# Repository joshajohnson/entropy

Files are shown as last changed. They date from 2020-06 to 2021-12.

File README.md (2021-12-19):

# Entropy

## A 96% Southpaw keyboard, with split space and encoder support. 

Entropy started as a STM32 powered keyboard running QMK and enclosed in a FR4 and PLA case, but at the time of writing runs on a nRF52 and ZMK, tucked inside a stacked acrylic case.

ZMK enables wireless functionality, and you'll get upwards of 6 months battery life thanks to the 200uA sleep current.

It also supports up to 4 rotary incoders in 5 different positions, along with a myriad of layout options.

## Photos
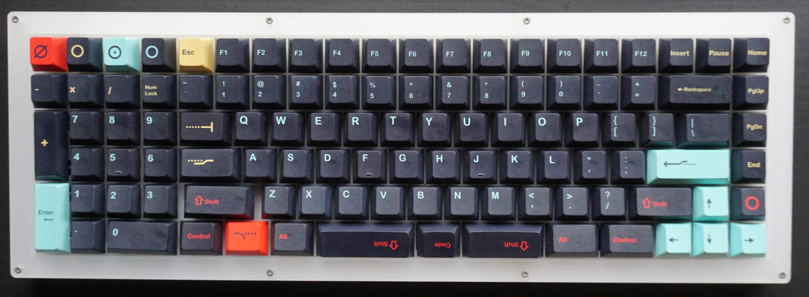
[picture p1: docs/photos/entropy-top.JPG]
Top View

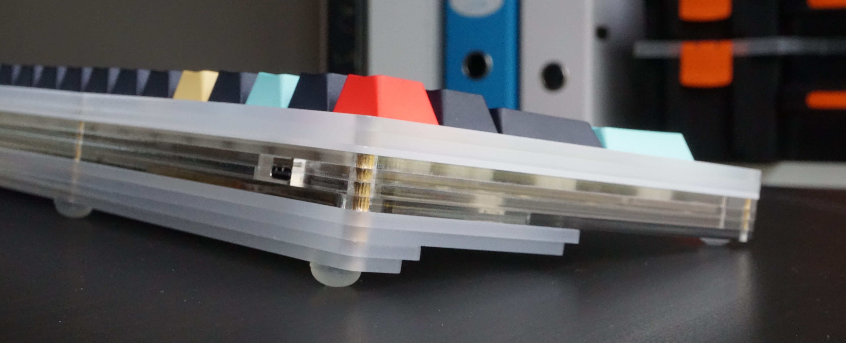
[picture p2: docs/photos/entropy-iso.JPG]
Side View

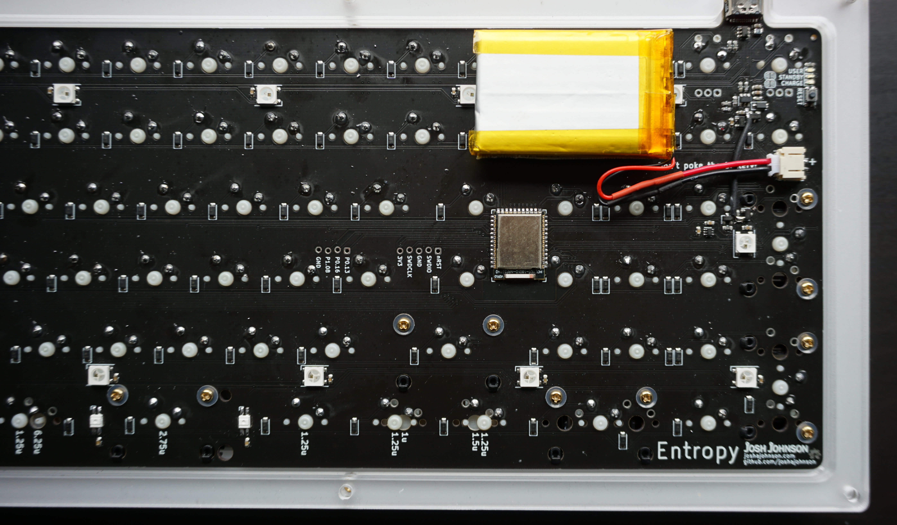
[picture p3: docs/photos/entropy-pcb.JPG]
Battery and Power Circuit


## Layout
Supports Encoders in (0,0)...(0,3) and (0,19)

ZMK versions only allow 4 encoders to be populated (hiting interrupt limit with 5 encoders)
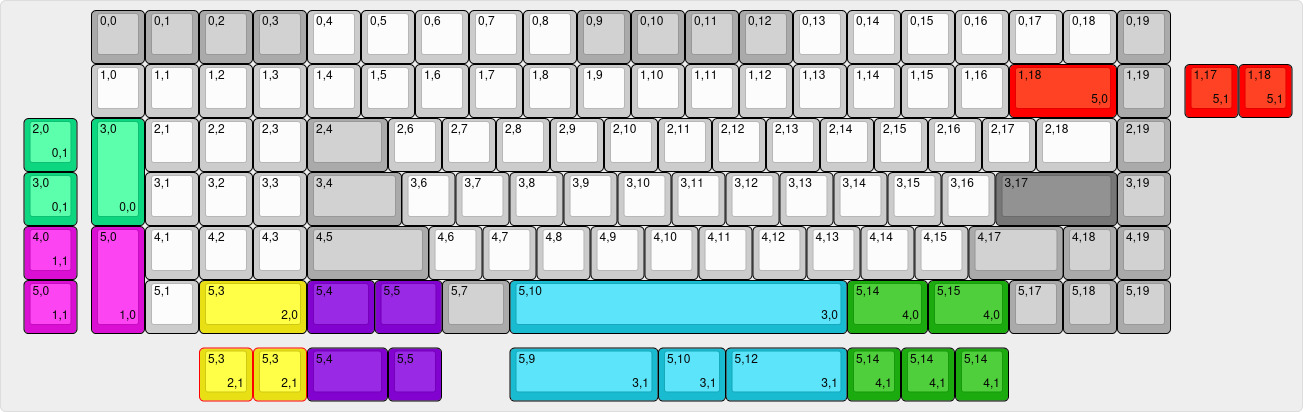
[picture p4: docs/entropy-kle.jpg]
KLE


## Revision History

R0.1: 
- Original STM32 design, no bugs that can't be worked around. 
- Tested and working.

R0.2: 
- Removed overengineering, modified to suit JLCSMT. 
- Fixed plate 2U tight fit. 
- **Has known issues with powering the LEDs, do not use**

### Image of R0.1 and R0.2 Design
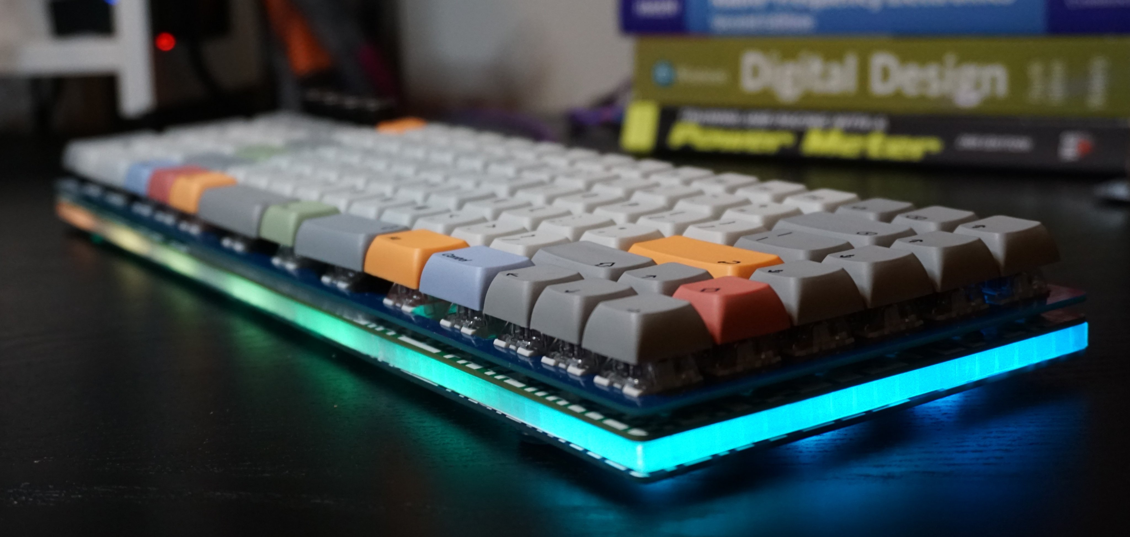
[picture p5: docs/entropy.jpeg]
R0.1 and R0.2 Assembled Keyboard


R0.3: 

- Moved to nRF52840 and ZMK due to supply issues with the STM32F303 used in R0.1 and R0.2.
- Case design changed to plate mount in stacked acrylic case.
- Design moved to KiCad V6.

R0.4: 
- Battery life and design improvements over R0.3. 
- Few issues requiring rework but suitable for use.

R0.5: 
- Resolved issues found in R0.4, however untested. 
- **Use at your own risk.**

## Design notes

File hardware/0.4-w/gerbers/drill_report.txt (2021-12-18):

Drill report for keyboard.kicad_pcb
Created on Sun Aug 29 18:12:00 2021

Copper Layer Stackup:
    =============================================================
    L1 :  F.Cu                      front
    L2 :  B.Cu                      back

Drill file 'keyboard.drl' contains
    plated through holes:
    =============================================================
    T1  0.300mm  0.0118"  (581 holes)
    T2  0.400mm  0.0157"  (81 holes)
    T3  0.600mm  0.0236"  (4 holes)  (with 4 slots)
    T4  1.000mm  0.0394"  (34 holes)
    T5  1.470mm  0.0579"  (230 holes)
    T6  1.500mm  0.0591"  (10 holes)

    Total plated holes count 940

Not plated through holes are merged with plated holes
    unplated through holes:
    =============================================================
    T7  0.650mm  0.0256"  (2 holes)
    T8  1.700mm  0.0669"  (10 holes)
    T9  1.750mm  0.0689"  (222 holes)
    T10  3.048mm  0.1200"  (18 holes)
    T11  3.988mm  0.1570"  (133 holes)
    T12  4.000mm  0.1575"  (5 holes)

    Total unplated holes count 390

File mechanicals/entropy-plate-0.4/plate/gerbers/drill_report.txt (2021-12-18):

Drill report for plate.kicad_pcb
Created on Sun Aug 29 19:39:39 2021

Copper Layer Stackup:
    =============================================================
    L1 :  F.Cu                      front
    L2 :  B.Cu                      back

Drill file 'plate.drl' contains
    plated through holes:
    =============================================================

    Total plated holes count 0

Not plated through holes are merged with plated holes
    unplated through holes:
    =============================================================
    T1  3.500mm  0.1378"  (8 holes)

    Total unplated holes count 8

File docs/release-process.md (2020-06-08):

# Board Release Process

* [ ] Ensure [Schematic Review](#schematic-review) is complete
* [ ] Ensure [Layout Review](#layout-review) is complete
* [ ] Component MPN / Supplier PN information added for all components
* [ ] PDF Schematic is exported from EESchema
* [ ] Rerun DRC and zone fills before exporting CAM files to ensure proper results
* [ ] Inspect layout in 3D viewer one last time
* [ ] Export gerber/drill, BOM, and PnP files by calling `make`
* [ ] Visually verify final CAM files to ensure no obvious misalignments, issues with paste and mask size / location

## Schematic Review
### General

* [ ] CAD ERC 100% clean. If some errors are invalid due to toolchain quirks, each exception must be inspected and signed
off as invalid
* [ ] Verify pin numbers of all schematic symbols against datasheet or external interface specification document (if not yet board proven)
* [ ] Schematic symbol matches chosen component package

#### Passive components
* [ ] Power/voltage/tolerance ratings specified as required
* [ ] Ceramic capacitors appropriately de-rated for C/V curve
* [ ] Polarized components specified in schematic if using electrolytic caps etc

### Power supply

* [ ] Fusing and/or reverse voltage protection at system power inlet

#### Regulators

* [ ] Verify estimated power usage per rail against regulator rating
* [ ] Linear regulators are stable with selected output cap ESR
* [ ] Confirm power rail sequencing against device datasheets

#### Decoupling
* [ ] Decoupling present for all ICs
* [ ] Decoupling meets/exceeds vendor recommendations if specified
* [ ] Bulk decoupling present at PSU

#### General
* [ ] All power inputs fed by correct voltage
* [ ] Check high-power discrete semiconductors and passives to confirm they can handle expected load
* [ ] Analog rails filtered/isolated from digital circuitry as needed

### Signals

#### Digital

* [ ] Signals are correct logic level for input pin
* [ ] Pullups on all open-drain outputs
* [ ] Termination on all high-speed signals
* [ ] TX/RX paired correctly for UART, SPI, MGT, etc
* [ ] Differential pair polarity / pairing correct
* [ ] Active high/low enable signal polarity correct

#### Clocks

* [ ] Correct load caps provided for discrete crystals
* [ ] Crystals only used if IC has an integrated crystal driver

#### Strap/init pins
* [ ] Pullup/pulldowns on all signals that need defined state at boot
* [ ] Strap pins connected to correct rail for desired state
* [ ] JTAG/ICSP connector provided for all programmable devices
* [ ] Reference resistors correct value and reference rail

#### External interface protection

* [ ] Power outputs (USB etc) current limited
* [ ] ESD protection on data lines going off board

#### Debugging / reworkability

* [ ] Use 0-ohm resistors vs direct hard-wiring for strap pins when possible
* [ ] Provide multiple ground clips/points for scope probes
* [ ] Dedicated ground in close proximity to analog test points
* [ ] Test points on all power rails
* [ ] Test points on interesting signals which may need probing for bringup/debug

### Thermal

* [ ] Power estimates for all large / high power ICs
* [ ] Thermal calculations for all large / high power ICs
* [ ] Specify heatsinks as needed

## Layout Review 

### General

* [ ] [Schematic review](#schematic-review) complete and signed off, including pin swaps done during layout
* [ ] Layout DRC 100% clean

### Decoupling

* [ ] Decoupling caps as close to power pins as possible
* [ ] Low inductance mounting used for decoupling (prefer ViP if available, otherwise "[]8" shaped side vias

### DFM / yield enhancement

* [ ] All design rules within manufacturer's capability
* [ ] Minimize use of vias/traces that push fab limits
* [ ] Layer number markers specified to ensure correct assembly
* [ ] Fiducials present (on both sides of board) if targeting automated assembly
* [ ] Fiducial pattern asymmetric to detect rotated or flipped boards
* [ ] Soldermask/copper clearance on fiducials respected
* [ ] Panelization completed if required
* [ ] Teardrops added to PTH components / vias

### Footprints

* [ ] Confirm components are available in the selected package
* [ ] Verify schematic symbol matches the selected package
* [ ] Confirm pinout diagram is from top vs bottom of package
* [ ] PCB printed 1:1 on paper and checked against physical parts OR
* [ ] 3D models obtained (if available) and checked against footprints
* [ ] Soldermask apertures on all SMT lands and PTH pads

### Differential pairs
* [ ] Routed differentially
* [ ] Skew matched if required
* [ ] Correct clearance to non-coupled nets

### High-speed signals

* [ ] Sufficient clearance to potential aggressors
* [ ] Length matched if required
* [ ] Minimize crossing reference plane splits/slots or changing layers, use caps/stitching vias if unavoidable
* [ ] Double-check pad width on connectors and add plane cutouts if needed to minimize impedance discontinuities

### Power
* [ ] Minimal slots in planes from via antipads
* [ ] Sufficient width for planes/traces for required current

### Mechanical
* [ ] Confirm all connectors to other systems comply with the appropriate mechanical standard (connector orientation, key position, etc)
* [ ] LEDs, buttons, and other UI elements on outward-facing side of board
* [ ] Keep-outs around PCB perimeter, card guides, panelization mouse-bites, etc respected
* [ ] Stress-sensitive components (MLCC) sufficiently clear from V-score or mouse bite locations, and oriented to reduce bending stress
* [ ] Clearance around large ICs for heatsinks/fans if required
* [ ] Clearance around pluggable connectors for mating cable/connector
* [ ] Clearance around mounting holes for screws
* [ ] Plane keepouts and clearance provided for shielded connectors, magnetics, etc
* [ ] Confirm PCB dimensions and mounting hole size/placement against enclosure or card rack design
* [ ] Verify mounting hole connection/isolation
* [ ] Components not physically overlapping/colliding
* [ ] STEP file exported and mechanical fit confirmed with mechanical CAD model

### Thermal

* [ ] Thermal reliefs used for plane connections (unless via is used for heatsinking)
* [ ] Solid connections used to planes if heatsinking
* [ ] Ensure thermal balance on SMT chip components to minimize risk of tombstoning

### Solder paste

* [ ] No uncapped vias in pads (except low-power QFNs where some voiding is acceptable)
* [ ] QFN paste prints segmented
* [ ] Small pads 100% size, larger pads reduced to avoid excessive solder volume

### Solder mask

* [ ] Adequate clearance around pads
* [ ] NOTE: Default in KiCad is far too large, decrease to between 0 and 50um

### Silkscreen

* [ ] Text size within fab limits
* [ ] Text not overlapping drills or component pads
* [ ] Text removed entirely in, or moved outside of, high component/via density areas
* [ ] Designer details / OSHW logo / project name / graphical assets on board
* [ ] Traceability markings (rev, date, name, etc) provided
* [ ] PCB Fab marking location denoted (if required)
* [ ] Silkscreen box provided for writing/sticking serial number
* [ ] Text mirrored properly on bottom layer

Huge thanks to [Andrew Zonenberg](https://github.com/azonenberg/pcb-checklist) whose PCB checklist was modified for use in this document.

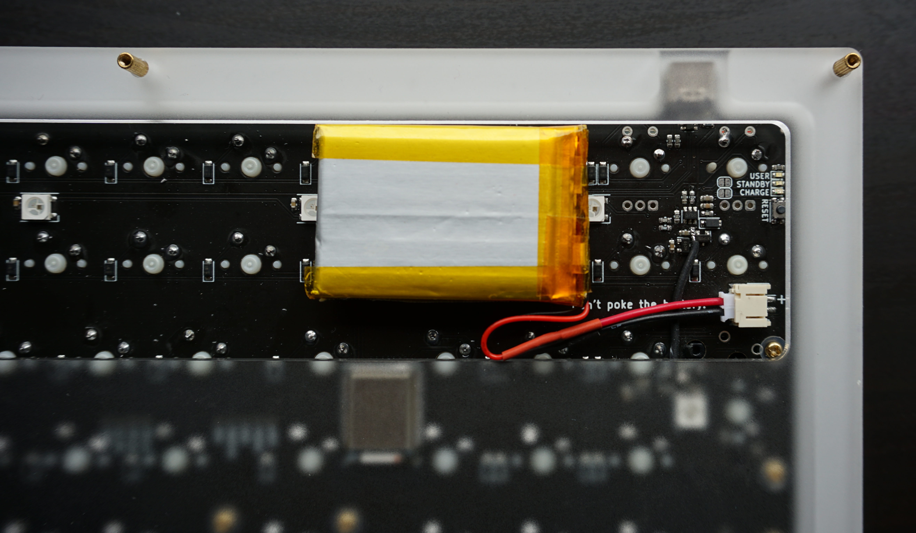
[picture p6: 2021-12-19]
docs/photos/entropy-battery-close.JPG

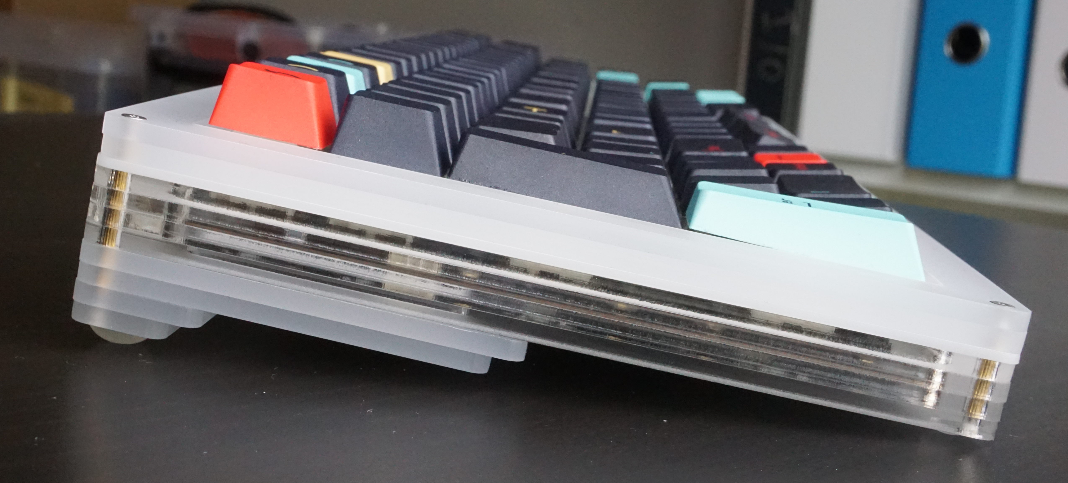
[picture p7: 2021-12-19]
docs/photos/entropy-side.JPG

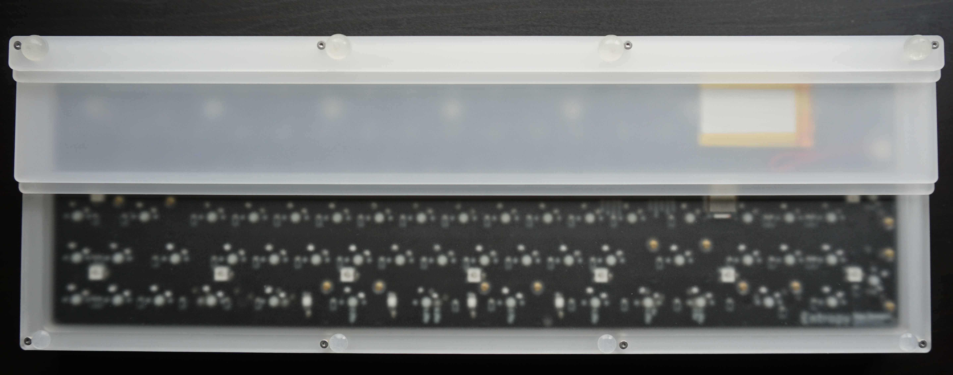
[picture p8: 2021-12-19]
docs/photos/entropy-bottom.JPG

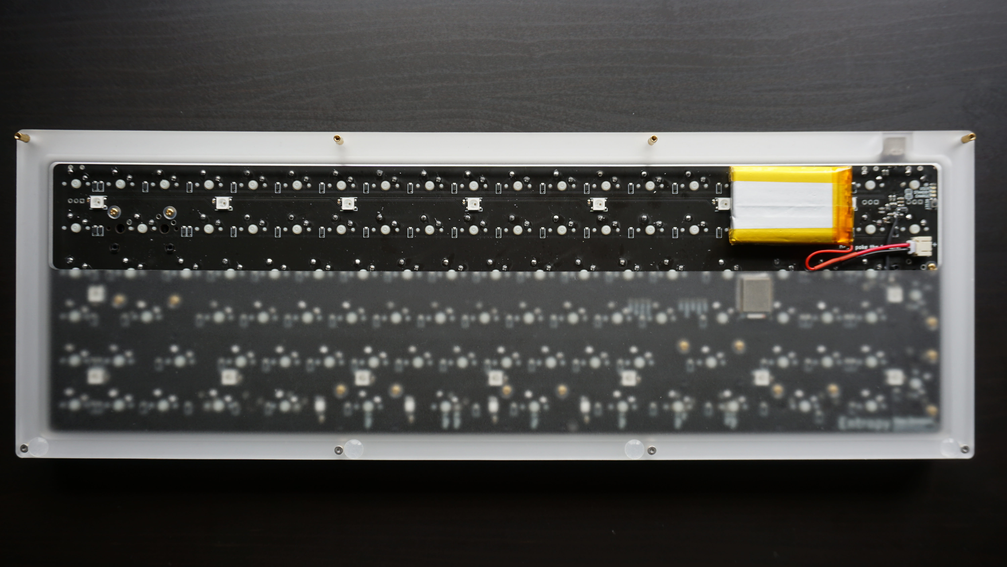
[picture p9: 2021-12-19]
docs/photos/entropy-battery-cover.JPG

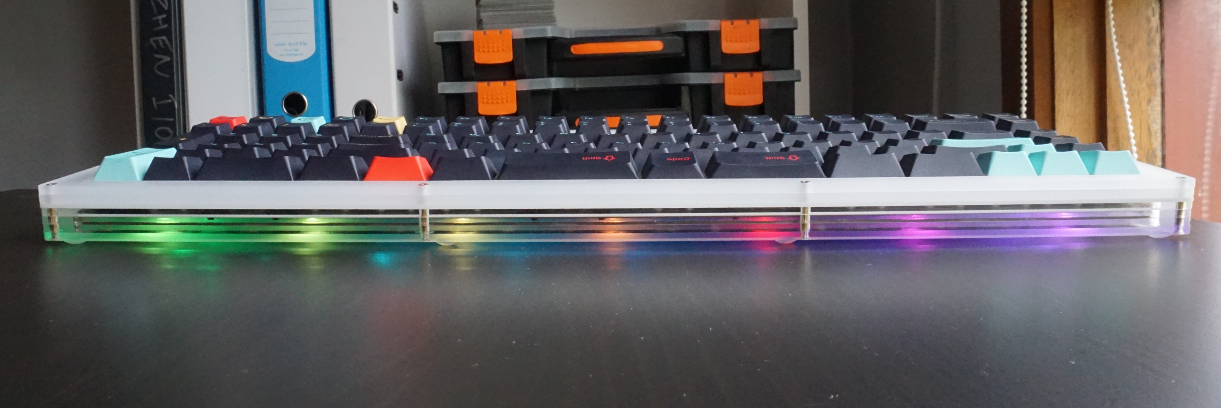
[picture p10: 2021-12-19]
docs/photos/entropy-front.JPG

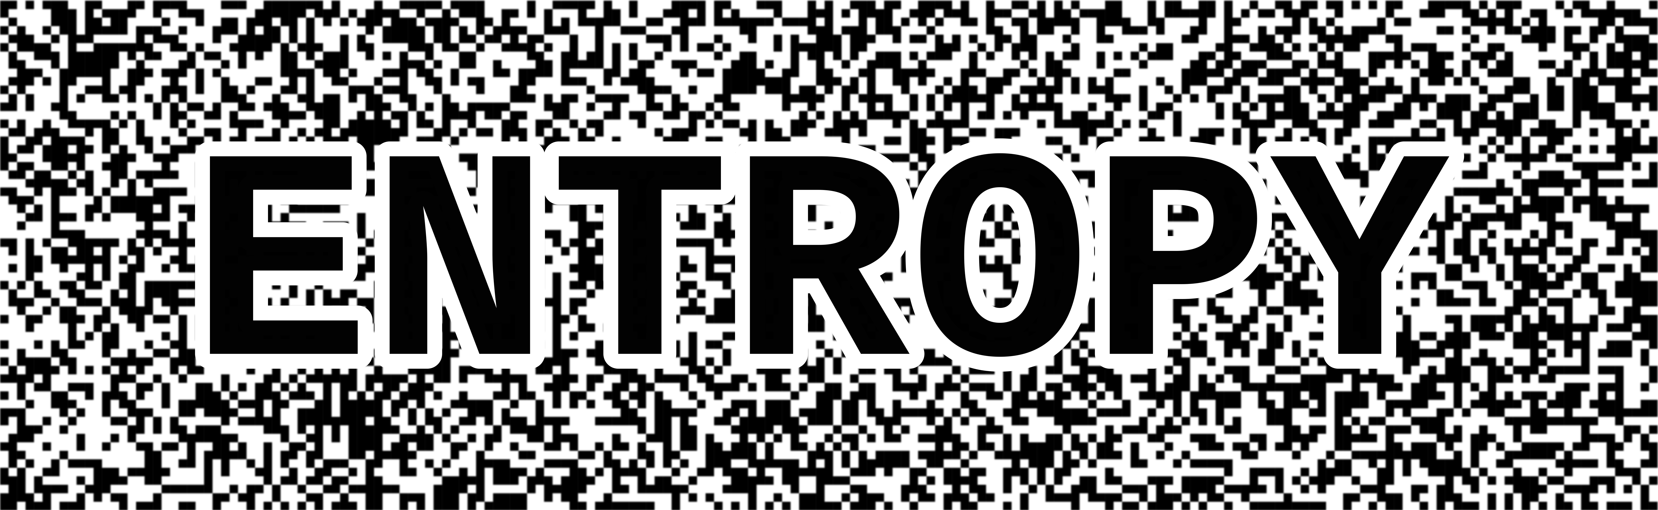
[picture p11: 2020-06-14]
graphics/pcb_export.png

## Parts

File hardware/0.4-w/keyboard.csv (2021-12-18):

Comment | Designator | Footprint | LCSC
100n | C1,C2,C3,C4,C5,C6,C7,C8,C9,C10,C11,C12,C13,C14,C15,C16,C17,C18,C19,C20,C23,C27 | Capacitor_SMD:C_0603_1608Metric | C14663
1u | C21,C26 | Capacitor_SMD:C_0603_1608Metric | C15849
10u | C22,C24,C25 | Capacitor_SMD:C_0603_1608Metric | C19702
SK6812-MINI-E | D1,D2,D3,D4 | josh-led:SK8612-MINI-E
B5817WL | D21 | josh-passives-smt:D_SOD-123FL | C122853
BLU | D22 | LED_SMD:LED_0603_1608Metric | C72041
GRN | D23 | LED_SMD:LED_0603_1608Metric | C72043
ORG | D24 | LED_SMD:LED_0603_1608Metric | C2286
WS2812C | D5,D6,D7,D8,D9,D10,D11,D12,D13,D14,D15,D16,D17,D18,D19,D20 | josh-led:LED_WS2812B_PLCC4_5.0x5.0mm_P3.2mm | C114587
1N4148 | D_1,D_2,D_3,D_4,D_5,D_6,D_7,D_8,D_9,D_10,D_11,D_12,D_13,D_14,D_15,D_16,D_17,D_18,D_19,D_20,D_21,D_22,D_23,D_24,D_25,D_26,D_27,D_28,D_29,D_30,D_31,D_32,D_33,D_34,D_35,D_36,D_37,D_38,D_39,D_40,D_41,D_42,D_43,D_44,D_45,D_46,D_47,D_48,D_49,D_50,D_51,D_52,D_53,D_54,D_55,D_56,D_57,D_58,D_59,D_60,D_61,D_62,D_63,D_64,D_65,D_66,D_67,D_68,D_69,D_70,D_71,D_72,D_73,D_74,D_75,D_76,D_77,D_78,D_79,D_80,D_81,D_82,D_83,D_84,D_85,D_86,D_87,D_88,D_89,D_90,D_91,D_92,D_93,D_94,D_95,D_96,D_97,D_98,D_99,D_100,D_101,D_102,D_103,D_104,D_105,D_106,D_107,D_108,D_109,D_110,D_111 | Diode_SMD:D_SOD-123 | C81598
500mA | F1 | josh-passives-smt:Fuse_0805_2012Metric | C66452
SWD | J1 | josh-connectors:5_PIN_THT_Staggered
USB_C_Receptacle_USB2.0 | J2 | josh-connectors:USB_C_Receptacle_HRO_TYPE-C-31-M-12 | C165948
JST_PH2 | J3 | josh-connectors:JST_PH_S2B-PH-SM4-TB_1x02-1MP_P2.00mm_Horizontal | C47647
Spare IO | J4 | josh-connectors:4_PIN_THT_Staggered
JMP | JP1,JP2 | Jumper:SolderJumper-2_P1.3mm_Bridged_RoundedPad1.0x1.5mm
Encoder_MX | K_1,K_9,K_15,K_22,K_113 | josh-keyboard:MX_KEYSWITCH_ENCODER
KEYSW | K_102 | josh-keyboard:MXOnly-1.75U-NoLED
KEYSW | K_2,K_3,K_5,K_6,K_8,K_10,K_11,K_12,K_13,K_14,K_16,K_17,K_18,K_19,K_20,K_23,K_26,K_27,K_28,K_29,K_34,K_35,K_37,K_38,K_39,K_40,K_41,K_42,K_44,K_45,K_46,K_47,K_48,K_49,K_50,K_51,K_52,K_53,K_55,K_56,K_57,K_58,K_59,K_60,K_61,K_62,K_63,K_65,K_67,K_68,K_69,K_70,K_71,K_72,K_73,K_74,K_75,K_77,K_78,K_79,K_80,K_81,K_82,K_83,K_84,K_85,K_86,K_87,K_89,K_90,K_91,K_92,K_93,K_94,K_95,K_96,K_98,K_99,K_100,K_101,K_103,K_104,K_105,K_109,K_110,K_111,K_112,K_114,K_115,K_116,K_117,K_118,K_121 | josh-keyboard:MXOnly-1U-NoLED
KEYSW | K_24,K_25 | josh-keyboard:MXOnly-1U-NoLED-3PIN
KEYSW | K_30,K_36,K_43,K_66 | josh-keyboard:MXOnly-1.25U-NoLED
KEYSW | K_31 | josh-keyboard:MXOnly-1.5U-NoLED-3PIN
KEYSW | K_32 | josh-keyboard:MXOnly-1.75U-NoLED-3PIN
KEYSW | K_33,K_76,K_106 | josh-keyboard:MXOnly-2.25U-NoLED
KEYSW | K_4,K_7,K_21,K_107 | josh-keyboard:MXOnly-2U-NoLED
KEYSW | K_54 | josh-keyboard:MXOnly-2.75U-NoLED
KEYSW | K_64 | josh-keyboard:MXOnly-6.25U-NoLED
KEYSW | K_88,K_97,K_108,K_120 | josh-keyboard:MXOnly-1.5U-NoLED
Josh-Details | LOGO1 | josh-logos:josh-details
Josh-Logo | LOGO2 | josh-logos:josh-johnson-logo-17x3
OSHW Logo | LOGO3 | josh-logos:OSHW_Logo_3.6x3.6_F.Mask
2N7002 | Q1 | Package_TO_SOT_SMD:SOT-23 | C8545
AO3401A | Q2,Q3 | Package_TO_SOT_SMD:SOT-23 | C15127
806K | R1,R10 | Resistor_SMD:R_0603_1608Metric | C23250
2M | R2 | Resistor_SMD:R_0603_1608Metric | C22976
5K1 | R3,R4,R5,R6,R7,R9 | Resistor_SMD:R_0603_1608Metric | C23186
2K | R8,R11 | Resistor_SMD:R_0603_1608Metric
RESET | SW1 | josh-buttons-switches:SW_Push_KMR2 | C99271
nRF52840_holyiot_18010 | U1 | josh-module:nRF52840_holyiot_18010
SN74LVC1T45DBV | U2 | Package_TO_SOT_SMD:SOT-363_SC-70-6 | C7843
XC6206P332MR | U3 | Package_TO_SOT_SMD:SOT-23 | C5446
SRV05-4 | U4 | Package_TO_SOT_SMD:SOT-23-6 | C85364
TP4057 | U5 | Package_TO_SOT_SMD:SOT-23-6 | C12044

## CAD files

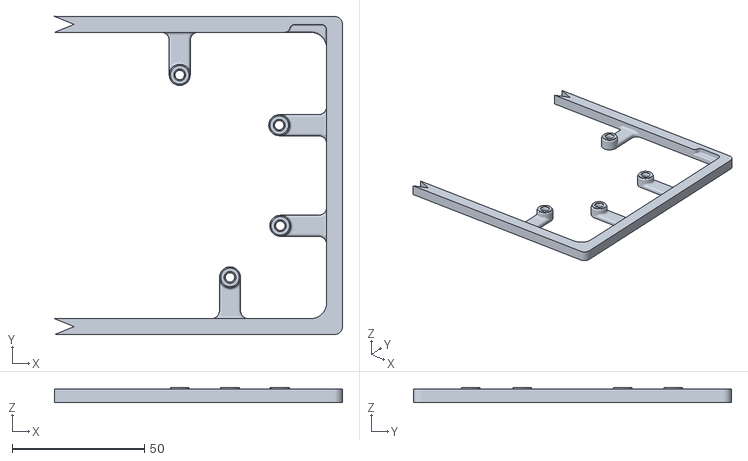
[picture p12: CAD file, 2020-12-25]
mechanicals/entropy-case-0.1/right_diffuser.stl
108.8 x 120.2 x 5.50

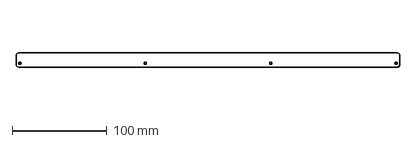
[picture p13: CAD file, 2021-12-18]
mechanicals/entropy-case-0.3/base-4.dxf
405.9 x 15.0 mm

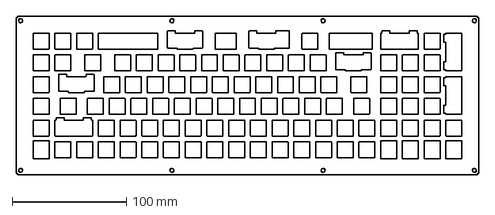
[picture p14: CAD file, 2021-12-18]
mechanicals/entropy-plate-0.4/plate.dxf
405.9 x 139.3 mm

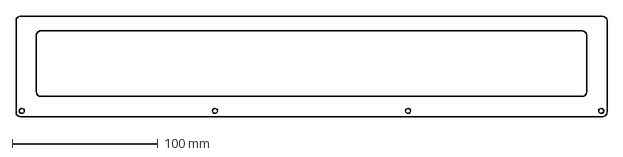
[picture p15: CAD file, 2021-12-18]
mechanicals/entropy-case-0.3/base-1.dxf
405.9 x 69.0 mm

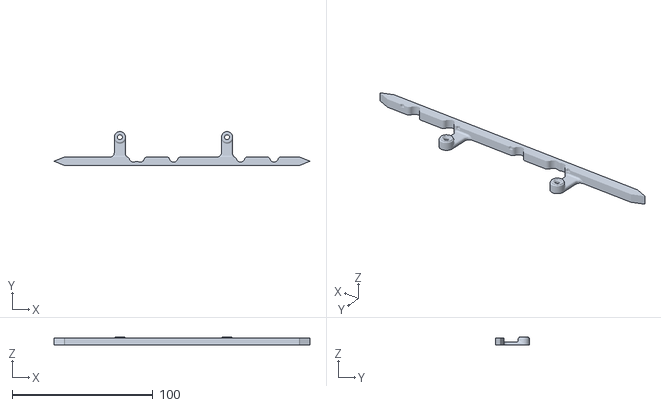
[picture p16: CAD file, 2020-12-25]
mechanicals/entropy-case-0.1/front_diffuser.stl
182.2 x 24.1 x 5.50

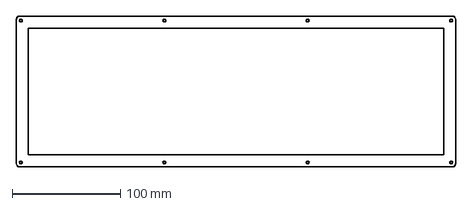
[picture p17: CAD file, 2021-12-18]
mechanicals/entropy-case-0.3/plate+2.dxf
405.9 x 139.3 mm

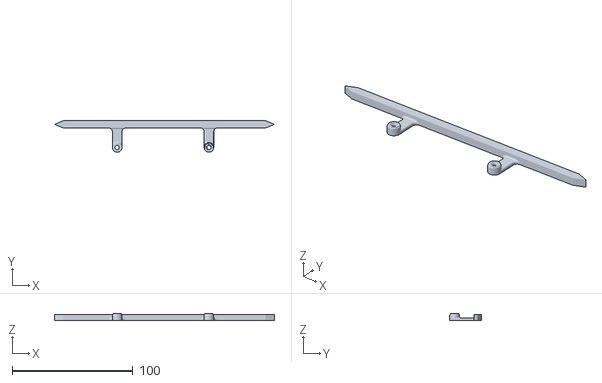
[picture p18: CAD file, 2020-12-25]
mechanicals/entropy-case-0.1/back_diffuser.stl
182.2 x 26.1 x 5.50

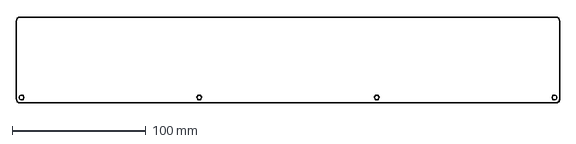
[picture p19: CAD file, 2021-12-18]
mechanicals/entropy-case-0.3/base-2.dxf
405.9 x 64.0 mm

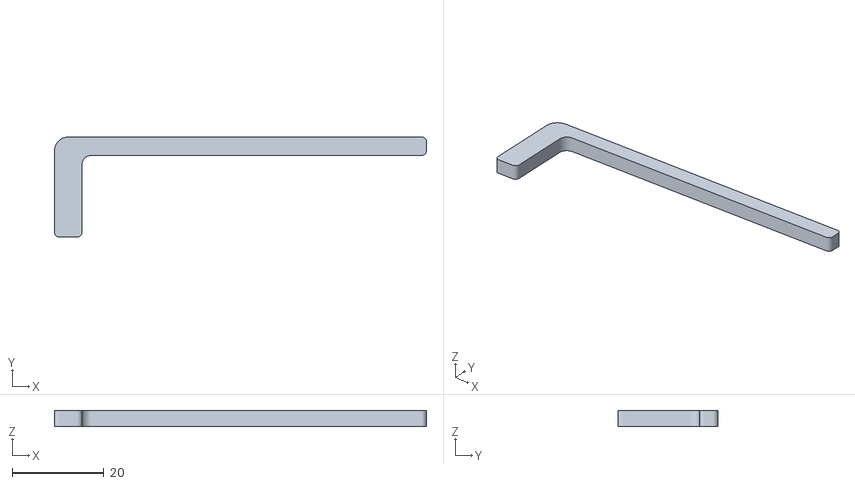
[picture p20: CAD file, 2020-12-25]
mechanicals/entropy-case-0.1/encoder_spacer.stl
81.0 x 21.8 x 3.50

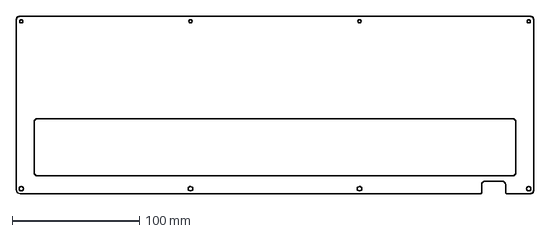
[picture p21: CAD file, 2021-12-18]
mechanicals/entropy-case-0.3/base.dxf
405.9 x 139.3 mm

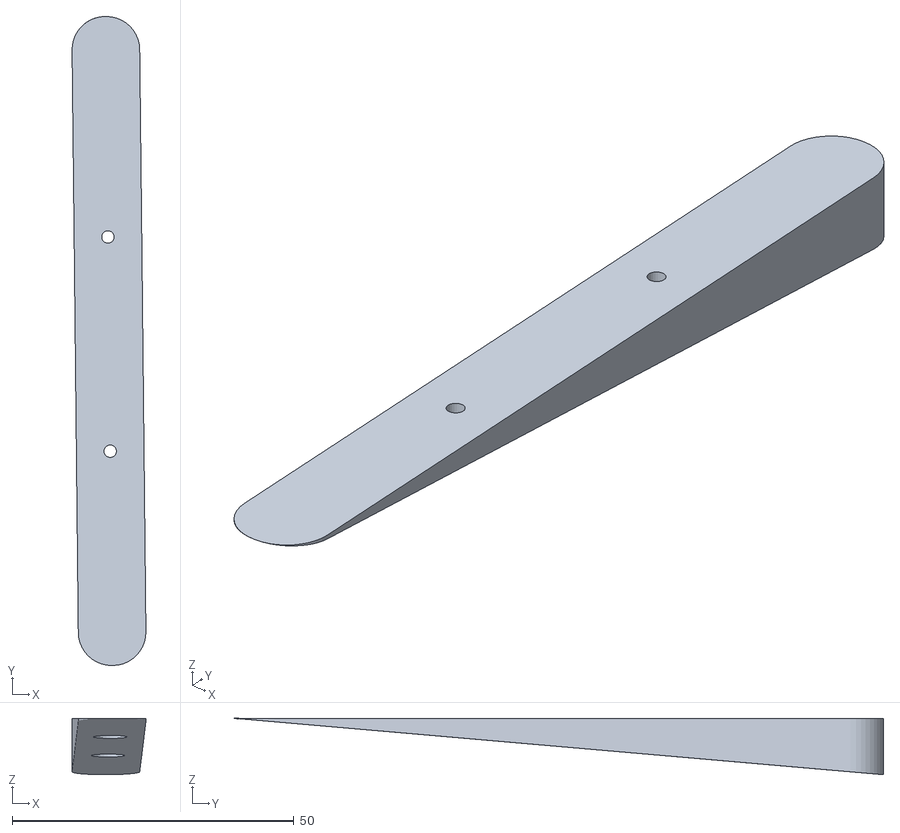
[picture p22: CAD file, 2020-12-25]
mechanicals/entropy-case-0.1/incline_spacer.stl
13.1 x 115.1 x 10.0

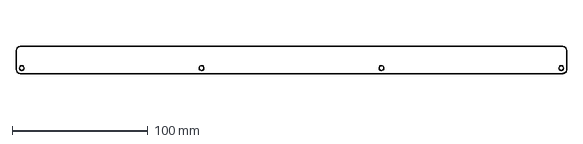
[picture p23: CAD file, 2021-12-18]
mechanicals/entropy-case-0.3/base-3.dxf
405.9 x 20.0 mm

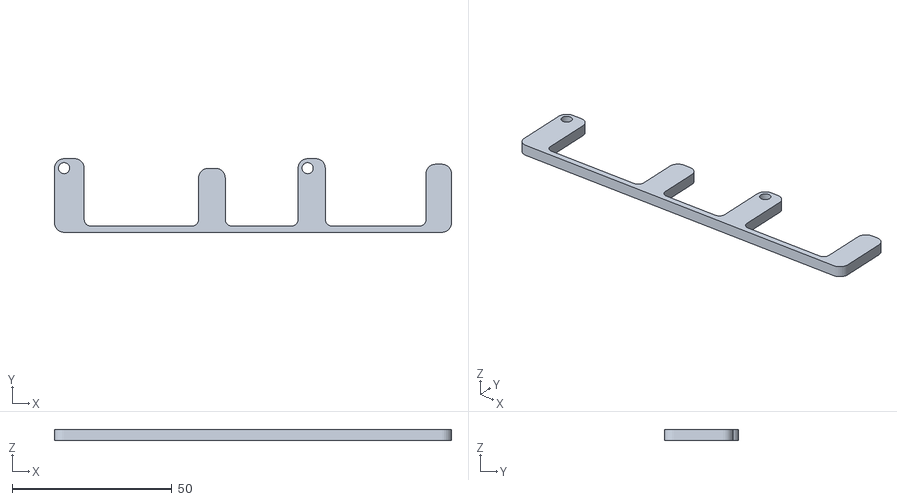
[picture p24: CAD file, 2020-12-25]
mechanicals/entropy-case-0.1/status_diffuser.stl
124.3 x 23.1 x 3.50

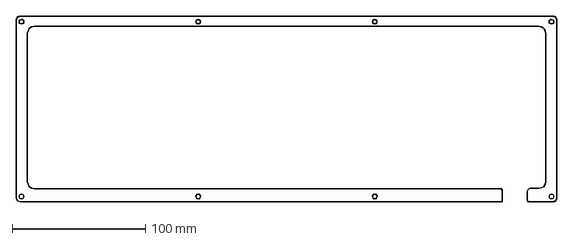
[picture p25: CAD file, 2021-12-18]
mechanicals/entropy-case-0.3/plate-3.dxf
405.9 x 139.3 mm

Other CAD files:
mechanicals/entropy-case-0.1/left_diffuser.stl
mechanicals/entropy-case-0.3/plate.dxf
mechanicals/entropy-case-0.3/plate+1.dxf
mechanicals/entropy-case-0.1/assembly.f3d
mechanicals/entropy-case-0.3/plate-1.dxf

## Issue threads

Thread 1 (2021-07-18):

0.3w Errata

joshajohnson, 2021-07-18:
### Bugs

- [X] Row3 should be moved to P0.08 (Pin 44) to keep all inputs on same port for power consumption.
- [X] One of the rotary encoders needs to be moved off port 0 due to limit of 8 interrupts per port. (move ENC_4)
- [X] 3V3 needs to be added to programming header for JLink to detect voltage

### Improvements

- [X] Add more RGB (WS2812C), place before SK6812-Mini-E in chain.
- [X] Check PFET has enough current carrying capacity for the LEDs (current one can do 4A)
- [X] Change level shifter to SN74LVC1T45DBV for lower quiescent current draw
- [X] Swap above part to SC70 due to component shortages
- [X] Add jumpers for Standby and Charge LEDs.
- [X] Change charge resistor values to 5k1, maybe decrease blue LED to 1k.
- [X] Swap 10K resistors for 5k1
- [X] Diode OR VBAT and VUSB into 3v3 regulator
- [X] ~Flip bottom stabs for a smaller PCB size / larger bezel.~
- [X] Breakout all unused pins
- [X] Extend USB connector by ~5mm (currently 6mm from flush)
- [X] Change case design per above

### TODO

- [x] Update bootloader to flash user LED ~(and maybe change direction of LED to active low?).~
- [X] Swap Green and Blue LEDs (so user is blue, standby is green).
- [X] Test fit acrylic case
- [X] Layout 0.4 PCB and order

Closed 2021-12-13.

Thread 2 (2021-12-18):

0.4w errata

joshajohnson, 2021-12-18:
All of the below should be fixed in 0.5w, but I'm yet to order and confirm.

- LEDs and level translator powered off VBAT, instead of VBAT or VUSB if device is plugged into USB
- Green STANDBY led is too bright, increased resistor from 5K1 to 10K
- Col 7 ran into 1.08 at the spare pin breakout header

Closed 2021-12-18.

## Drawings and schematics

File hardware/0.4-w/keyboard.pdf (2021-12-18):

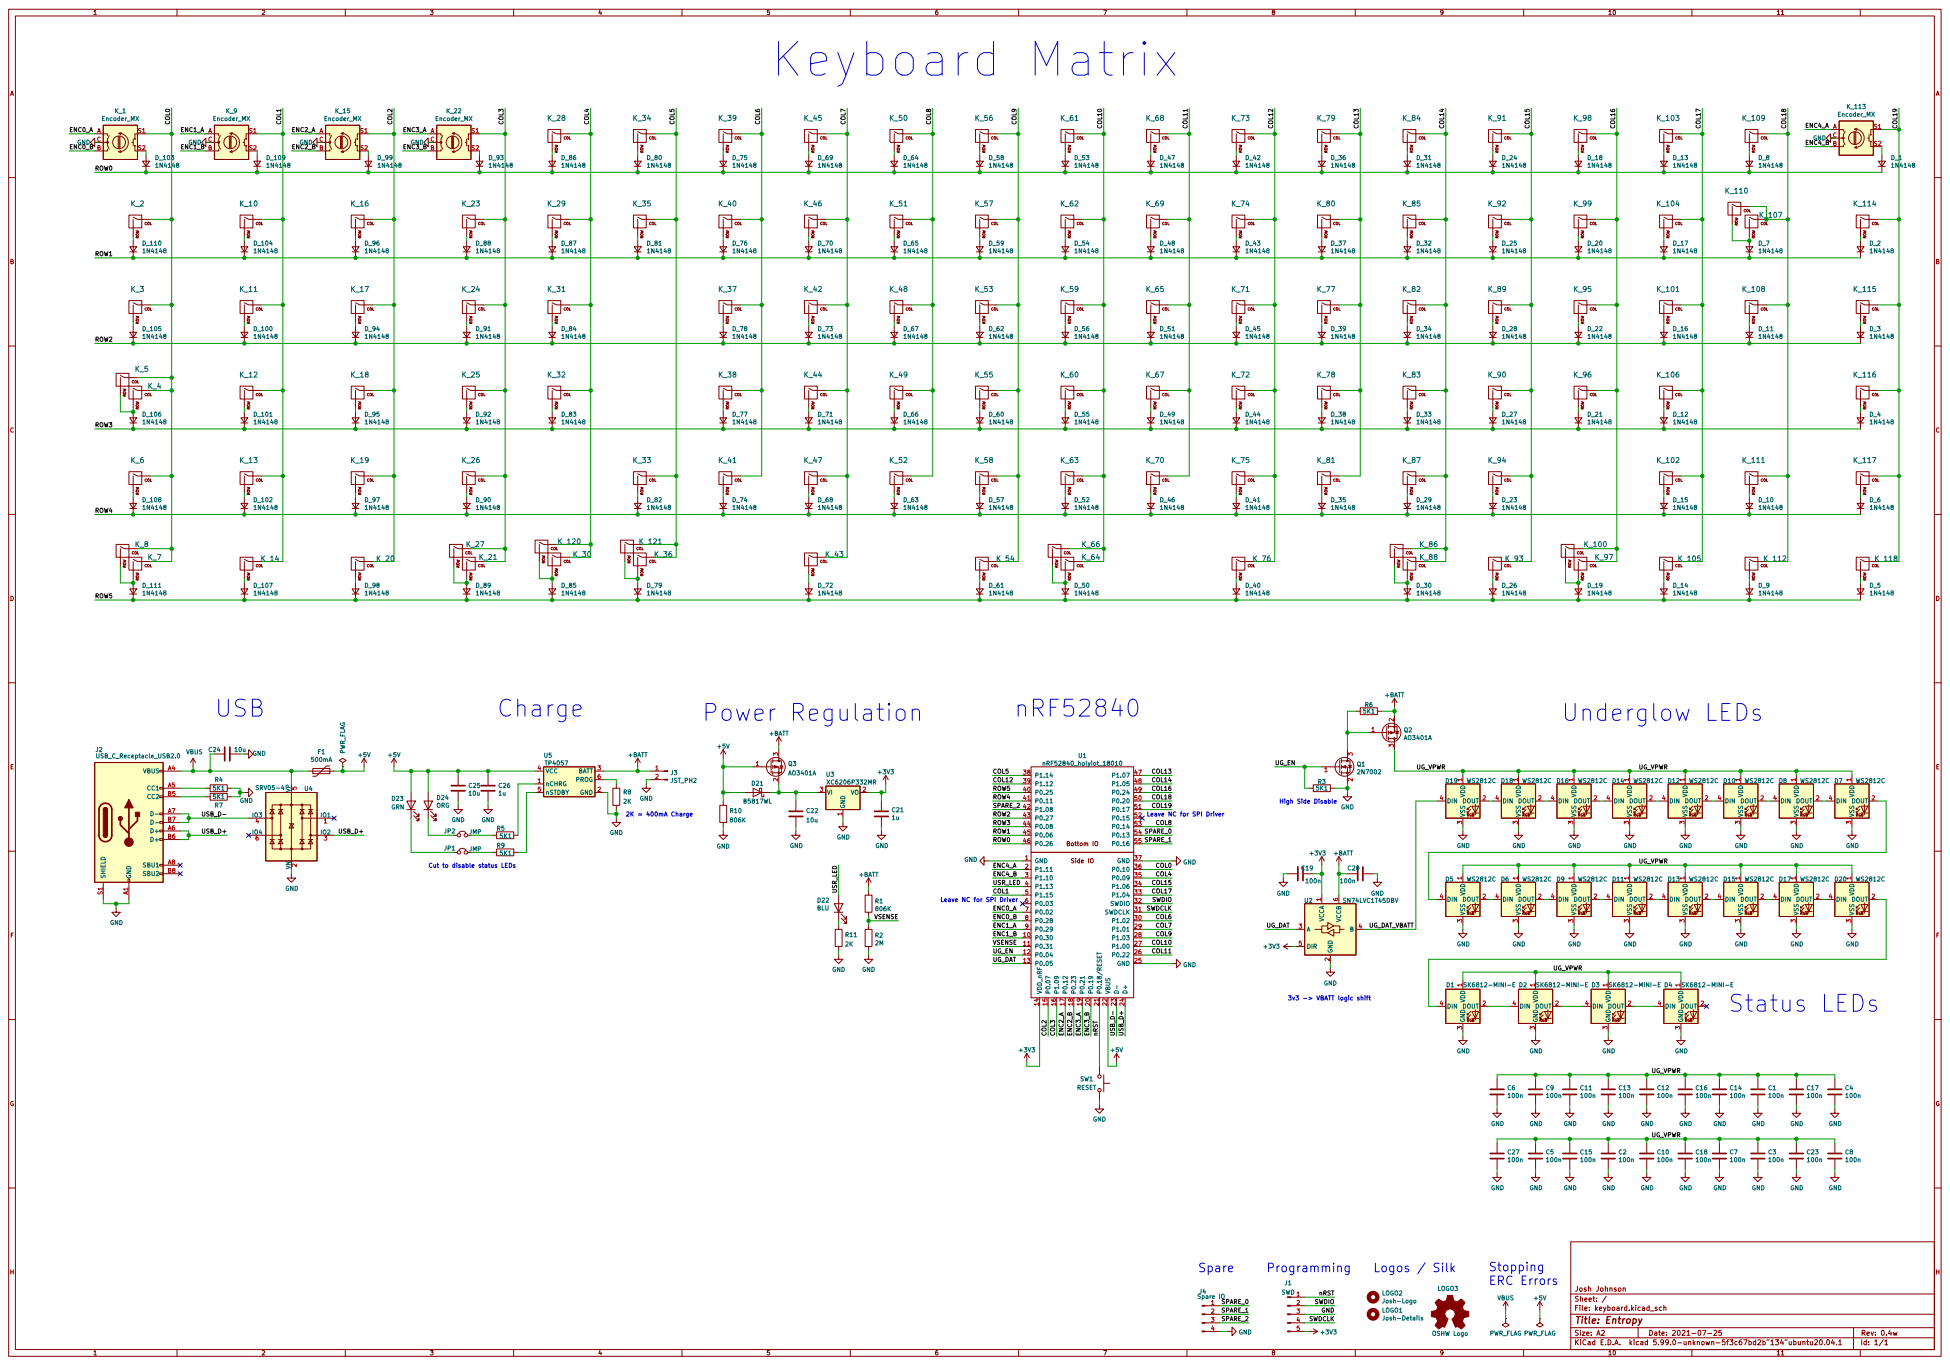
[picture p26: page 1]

Leave NC for SPI Driver 2K = 400mA Charge

File: keyboard.kicad_sch Sheet: / Josh Johnson

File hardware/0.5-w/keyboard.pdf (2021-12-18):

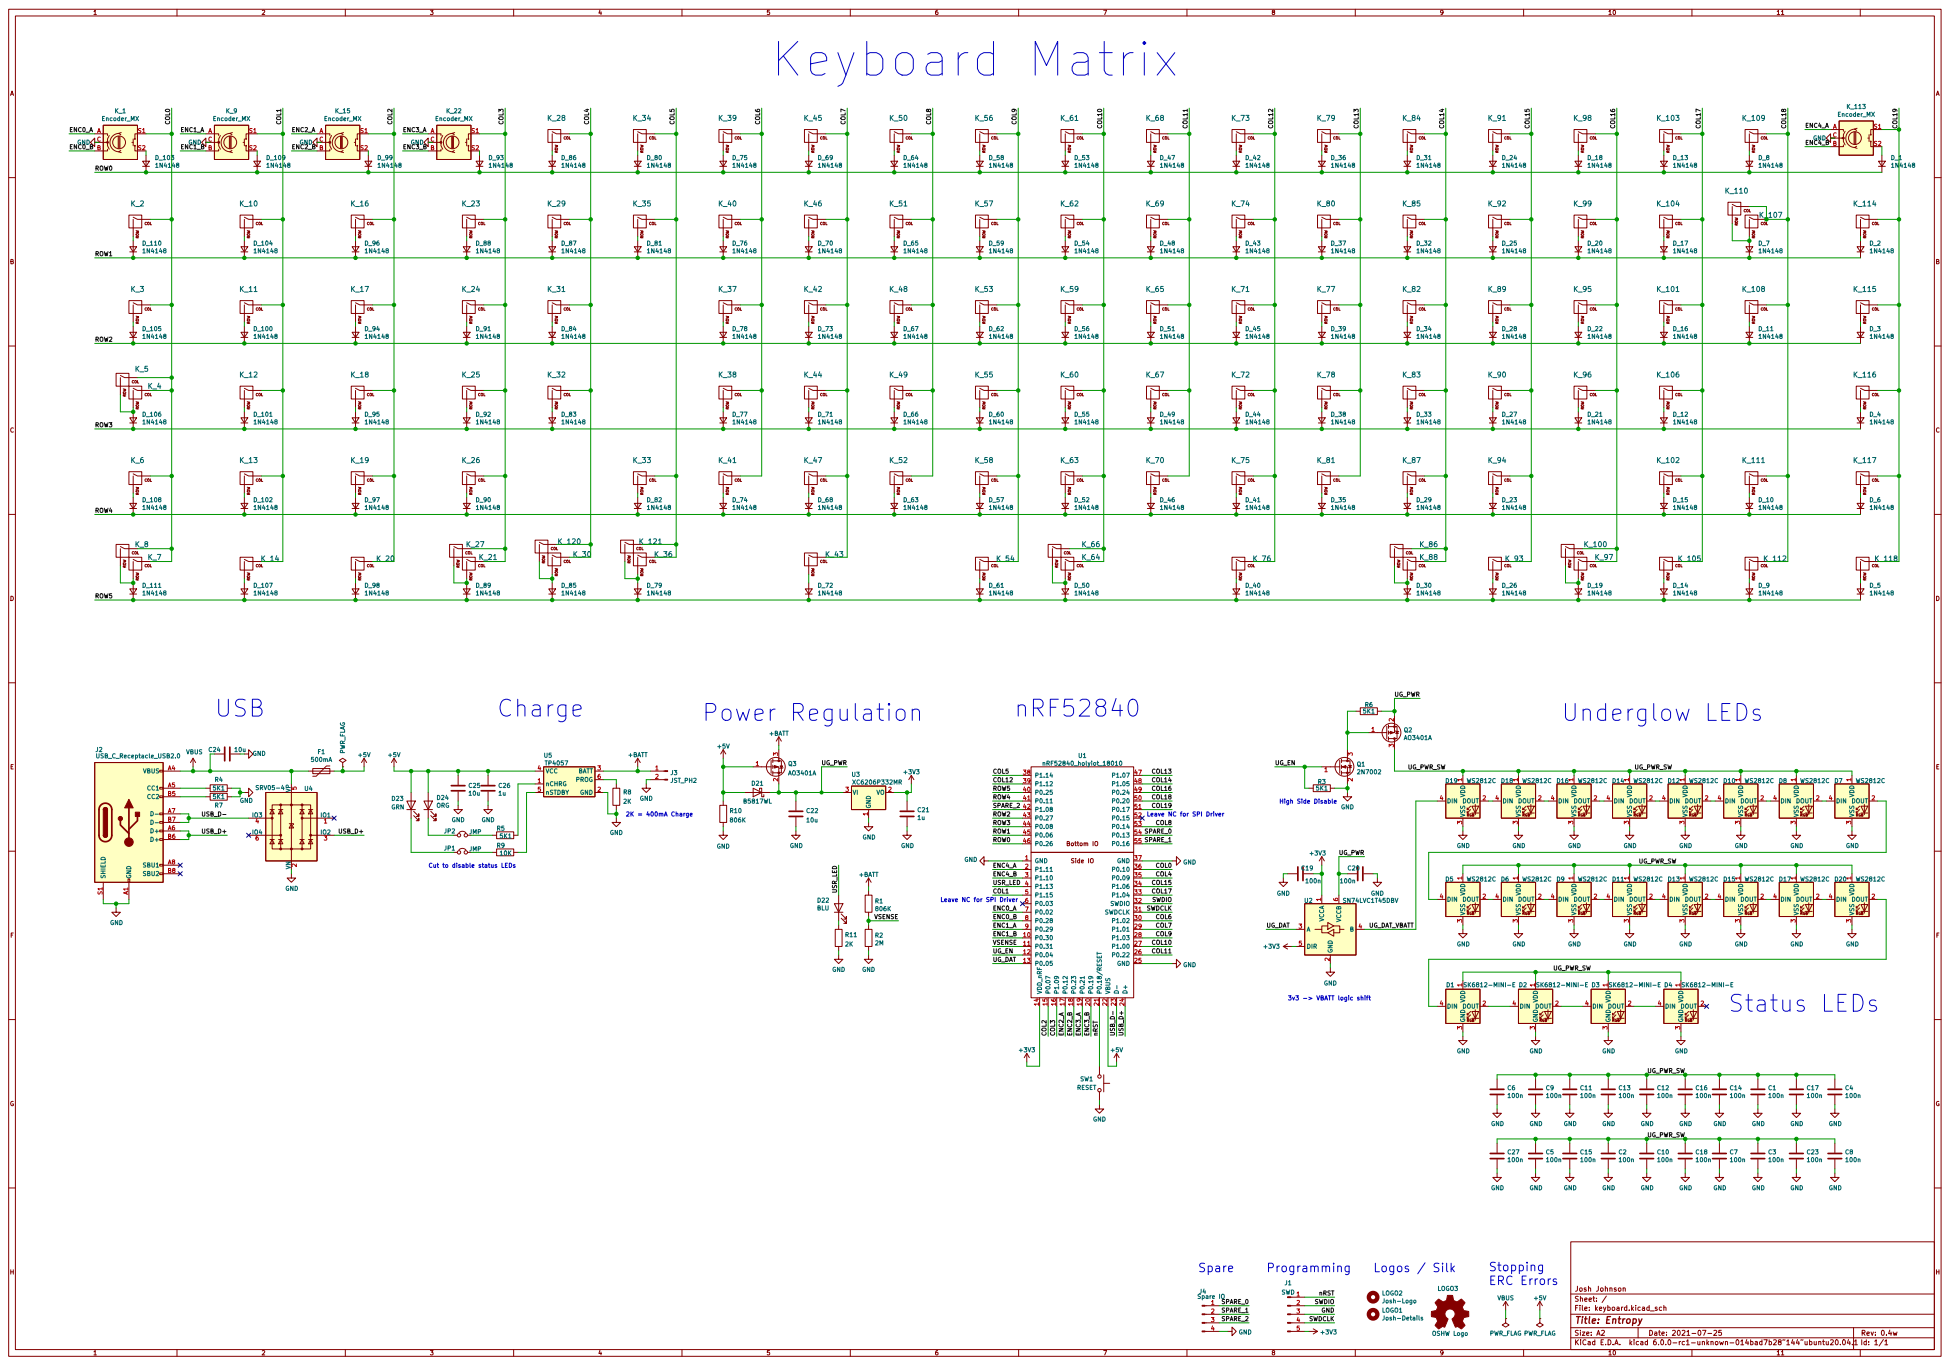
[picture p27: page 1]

Leave NC for SPI Driver Power Regulation

File: keyboard.kicad_sch Sheet: / Josh Johnson

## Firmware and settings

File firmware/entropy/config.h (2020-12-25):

/*
Copyright 2020 joshajohnson

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
You should have received a copy of the GNU General Public License
along with this program.  If not, see <http://www.gnu.org/licenses/>.
*/

#pragma once

#include "config_common.h"

/* USB Device descriptor parameter */
#define VENDOR_ID       0x6A6A  // JJ
#define PRODUCT_ID      0x1010  // Entropy?
#define DEVICE_VER      0x0001
#define MANUFACTURER    joshajohnson
#define PRODUCT         entropy
#define DESCRIPTION     entropy keyboard

/* key matrix */
#define MATRIX_ROWS 6
#define MATRIX_COLS 20

#define MATRIX_ROW_PINS { C10, C11, C12, B1, B0, C5 }
#define MATRIX_COL_PINS { B12, B11, B10, B2, B9, B8, C3, C2, C1, C0, C13, C14, C15, A3, A6, A7, C4, B3, B4, B5 }
#define UNUSED_PINS

#define DIODE_DIRECTION COL2ROW

/* Rotary Encoder Things */
// #define ENCODER_DIRECTION_FLIP
#define ENCODERS_PAD_A { B13, C7, C9, A10, B6 }
#define ENCODERS_PAD_B { B14, C8, A8,  A9, B7 }

/* Lighting things */
#define RGBLIGHT_LAYERS
#define RGBLIGHT_LAYERS_OVERRIDE_RGB_OFF

#define RGB_DI_PIN B15
#ifdef RGB_DI_PIN
  #define RGBLED_NUM 20
  #define RGBLIGHT_HUE_STEP 8
  #define RGBLIGHT_SAT_STEP 8
  #define RGBLIGHT_VAL_STEP 8
  #define RGBLIGHT_LIMIT_VAL 255 /* The maximum brightness level */
  #define RGBLIGHT_SLEEP  /* If defined, the RGB lighting will be switched off when the host goes to sleep */
/*== all animations enable ==*/
  #define RGBLIGHT_ANIMATIONS
/*== or choose animations ==*/
//   #define RGBLIGHT_EFFECT_BREATHING
  #define RGBLIGHT_EFFECT_RAINBOW_MOOD
  #define RGBLIGHT_EFFECT_RAINBOW_SWIRL
//   #define RGBLIGHT_EFFECT_SNAKE
//   #define RGBLIGHT_EFFECT_KNIGHT
//   #define RGBLIGHT_EFFECT_CHRISTMAS
//   #define RGBLIGHT_EFFECT_STATIC_GRADIENT
//   #define RGBLIGHT_EFFECT_RGB_TEST
//   #define RGBLIGHT_EFFECT_ALTERNATING
/*== customize breathing effect ==*/
  /*==== (DEFAULT) use fixed table instead of exp() and sin() ====*/
  #define RGBLIGHT_BREATHE_TABLE_SIZE 256      // 256(default) or 128 or 64
  /*==== use exp() and sin() ====*/
  #define RGBLIGHT_EFFECT_BREATHE_CENTER 1.85  // 1 to 2.7
  #define RGBLIGHT_EFFECT_BREATHE_MAX    255   // 0 to 255
#endif

/* Debounce reduces chatter (unintended double-presses) - set 0 if debouncing is not needed */
#define DEBOUNCE 5

/* Tap delay for tap vs hold */
#define TAPPING_TERM 200

/* Slow down key press speed to ensure computer picks it up */
#define TAP_CODE_DELAY 20

/* Audio Things */
#define AUDIO_CLICKY

/* Mouse Things */
#define MOUSEKEY_INTERVAL       20
#define MOUSEKEY_DELAY          300
#define MOUSEKEY_TIME_TO_MAX    100
#define MOUSEKEY_MAX_SPEED      3

/* Mechanical locking support. Use KC_LCAP, KC_LNUM or KC_LSCR instead in keymap */
#define LOCKING_SUPPORT_ENABLE
/* Locking resynchronize hack */
#define LOCKING_RESYNC_ENABLE

/* disable these deprecated features by default */
#ifndef LINK_TIME_OPTIMIZATION_ENABLE
  #define NO_ACTION_MACRO
  #define NO_ACTION_FUNCTION
#endif

// Status LED positions
#define LED0 16
#define LED1 17
#define LED2 18
#define LED3 19

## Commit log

2020-06-08 init, almost finished placing compenents
    [keyboard.kicad_pcb, keyboard.sch]
2020-06-08 continuing layout
    [keyboard.kicad_pcb, keyboard.sch]
2020-06-08 change name
    [keyboard.kicad_pcb, keyboard.sch]
2020-06-09 layout ++
    [keyboard.kicad_pcb, keyboard.sch]
2020-06-11 unrouted = 0 with no matrix - mcu connections
    [keyboard.kicad_pcb, keyboard.sch]
2020-06-13 layout done
    [keyboard.kicad_pcb, keyboard.sch]
2020-06-14 graphics added
    [keyboard.sch]
2020-06-14 partial upper plate done
    [keyboard.kicad_pcb, keyboard.sch, plate-rev0.dxf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]
2020-06-14 update mounting hole locations
    [keyboard.kicad_pcb, keyboard.sch]
2020-06-14 mechanical changes
    [keyboard.kicad_pcb, keyboard.sch]
2020-06-17 merged LEDs into one string
    [keyboard.sch]
2020-06-20 cleaning up schematic
    [keyboard.sch]
2020-06-21 add encoder top right
    [keyboard.kicad_pcb, keyboard.sch]
2020-06-25 add split backspace
    [keyboard.kicad_pcb, keyboard.sch]
2020-07-07 off to fab
    [keyboard.sch]
2020-12-25 r0.2 release, untested. Add firmware + VIA files
    [keyboard.kicad_pcb, keyboard.sch, plate-rev0.dxf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]
2020-12-25 add stl for case
    [back_diffuser.stl, encoder_spacer.stl, front_diffuser.stl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]
2020-12-25 add f3d
    [assembly.f3d]
2021-04-17 begun work on 0.3w
    [keyboard.kicad_sch]
2021-04-18 all parts placed
    [keyboard.kicad_sch]
2021-04-23 drc = erc = 0
    [keyboard.kicad_sch]
2021-04-25 added user led
    [keyboard.kicad_sch]
2021-04-25 added updated plate
    [keyboard.kicad_pcb, keyboard.kicad_sch]
2021-04-28 clean up layout
    [keyboard.kicad_sch]
2021-04-28 updated plate cutout for 3mm acrylic
    [keyboard.kicad_pcb]
2021-07-25 finalise 0.3w
    [keyboard.kicad_sch]
2021-07-25 0.4 first pass layout done
    [keyboard.kicad_sch]
2021-07-25 0.4w WIP layout
    [keyboard.kicad_pcb, keyboard.kicad_sch]
2021-07-26 clean up routing
    [keyboard.kicad_sch]
2021-12-18 0.4 cleanup and 0.5 addition of files
    [assembly.f3d, back_diffuser.stl, base-1.dxf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]

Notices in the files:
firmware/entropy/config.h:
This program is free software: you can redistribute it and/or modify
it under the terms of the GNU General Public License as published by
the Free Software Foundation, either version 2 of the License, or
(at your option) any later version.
